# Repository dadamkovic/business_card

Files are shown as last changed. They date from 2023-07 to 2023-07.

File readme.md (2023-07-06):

Project in Progress
----------------------------

A PCB for a simple, low profile business card. Intended to be
programmed with a few simple games. BOM cost as of version 0.1 is ~6$.

Includes: 
- 5 LEDs
- buzzer
- STM32F042F4Px (USB communication)

PCB has cutout for components that are inteded to be mounted 'body in'
to decrease the thickness of the PCB (1.2mm PCB used), to get close to
the business card compactness.

Pictures:

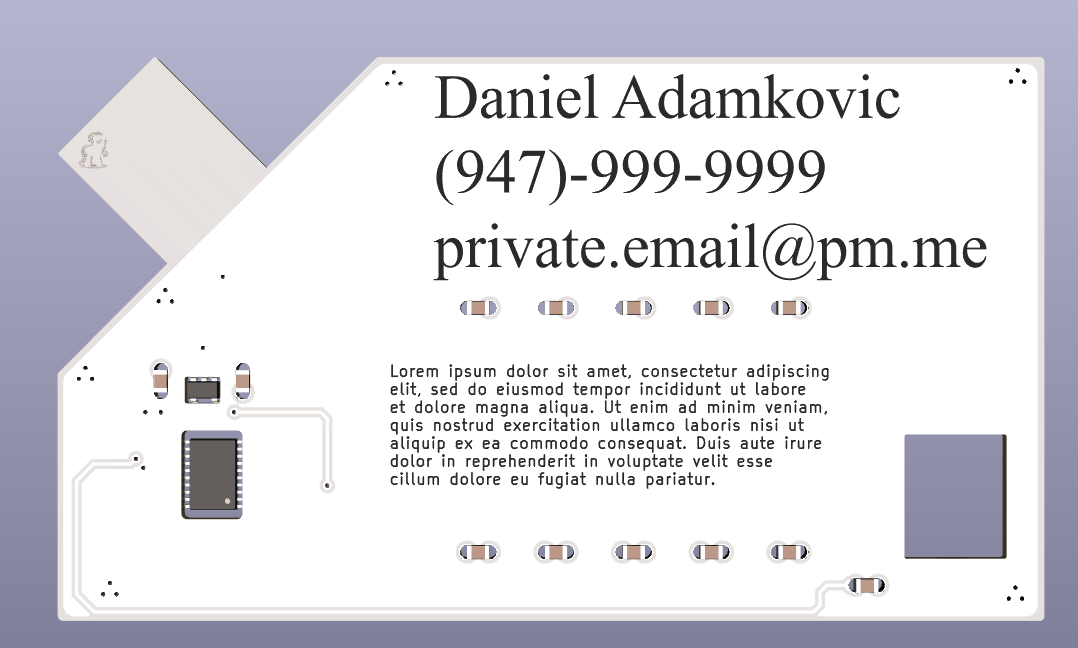
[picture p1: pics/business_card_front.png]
front side

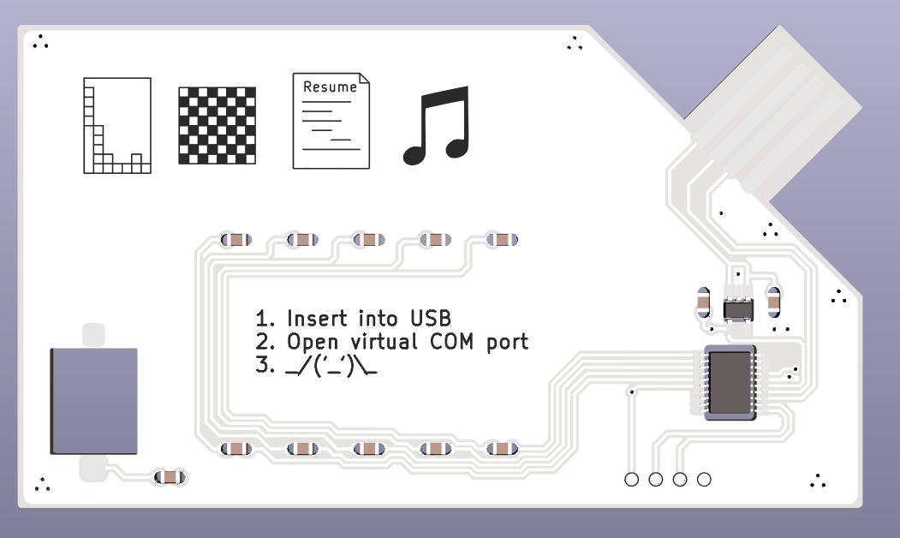
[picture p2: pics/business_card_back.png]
back side


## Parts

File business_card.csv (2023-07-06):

# | Reference | Qty | Value | Footprint | DNP | Source | Price
1 | BZ1 | 1 | Buzzer | User_Buzzer:Buzzer |  | https://www.mouser.com/ProductDetail/AATC/APD-1109-LF?qs=uwxL4vQweFP3stWKjDUYjg%3D%3D | 2.11
2 | C1, C2 | 2 | 1u | User_0805:C_0805_2012Metric |  | https://www.mouser.com/ProductDetail/Samsung-Electro-Mechanics/CL21B105KOFNFNE | 0.065
3 | D1, D2, D3, D4, D5 | 5 | LED | User_0805:C_0805_2012Metric
4 | J1 | 1 | Conn_01x04_Pin | User_PCB_Connector:USB_Conn
5 | R1, R2, R3, R4, R5 | 5 | 2k | User_0805:C_0805_2012Metric
6 | R6 | 1 | 700 | User_0805:C_0805_2012Metric
7 | TP1, TP2, TP3, TP4 | 4 | TestPoint | TestPoint:TestPoint_Pad_D1.0mm
8 | U1 | 1 | STM32F042F4Px | User_uC:Reverse TSSOP-20_4.4x6.5mm_P0.65mm |  | https://www.mouser.com/ProductDetail/STMicroelectronics/STM32F042F4P6?qs=4b8myOmUP%252BvvhAaQx2eFdg%3D%3D | 3.2
9 | U2 | 1 | MIC5504-1.2YM5 | User_Regulator:SOT-23-5 |  | https://www.mouser.com/ProductDetail/Microchip-Technology/MIC5504-3.3YM5-TR?qs=U6T8BxXiZAUmVQ5Zs217qQ%3D%3D | 0.25

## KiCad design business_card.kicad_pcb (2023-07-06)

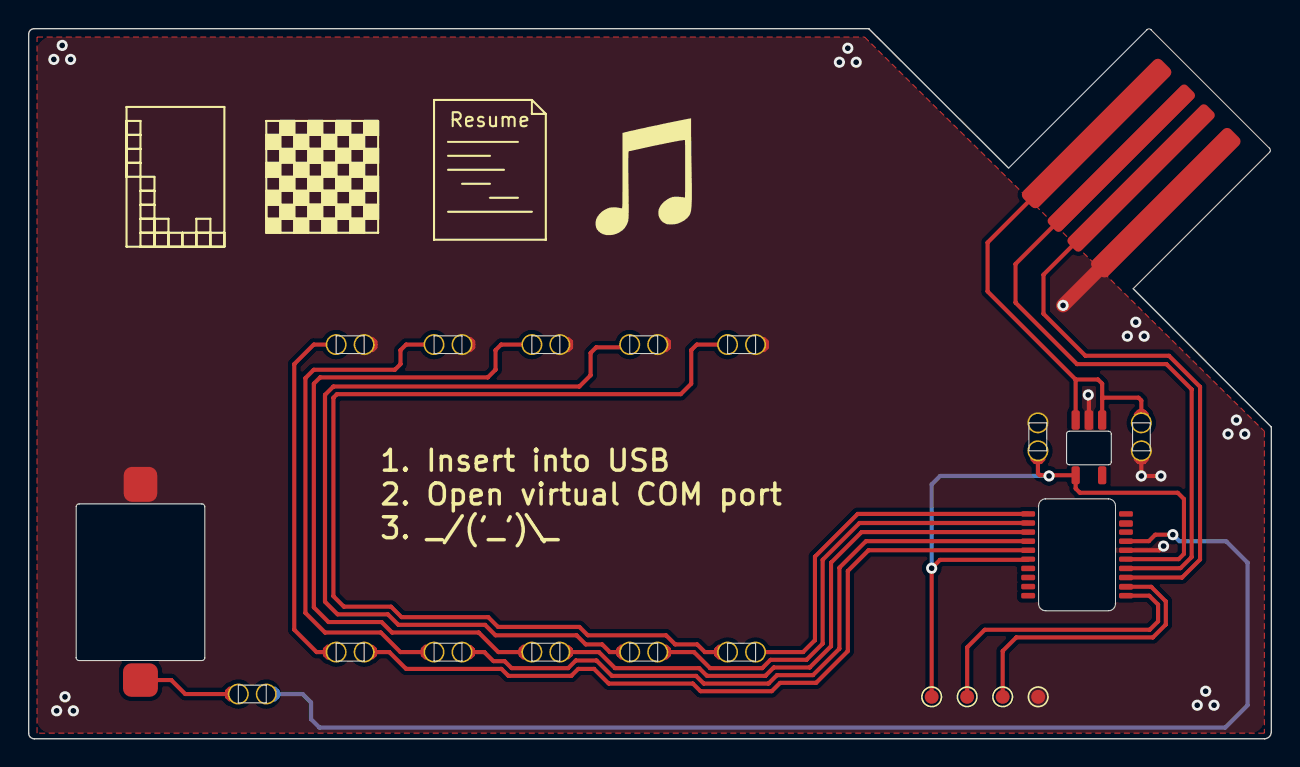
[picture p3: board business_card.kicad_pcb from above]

Board: 2 copper layers, 88.9 x 50.8 mm, 21 parts (0 on the bottom side), 19 nets.

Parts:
BZ1: Buzzer
C1, C2: C_Small; C_0805_2012Metric
D1, D2, D3, D4, D5: LED; C_0805_2012Metric
J1: Conn_01x04_Pin; USB_Conn
R1, R2, R3, R4, R5, R6: R_Small; C_0805_2012Metric
TP1, TP2, TP3, TP4: TestPoint; TestPoint_Pad_D1.0mm
U1: STM32F042F4Px; Reverse TSSOP-20_4.4x6.5mm_P0.65mm
U2: MIC5504-1.2YM5; SOT-23-5

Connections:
/3V3_SUPPLY: C2.1, TP1.1, U1.5 (VDDA), U1.16 (VDD), U2.5 (VOUT)
/5V_USB: C1.1, J1.1, U2.1 (VIN), U2.3 (EN)
/SWDCLK: TP3.1, U1.20 (PA14)
/SWDIO: TP2.1, U1.19 (PA13)
/USB_DM: J1.2, U1.17 (PA9/PA11)
/USB_DP: J1.3, U1.18 (PA10/PA12)
GND: BZ1.1 (-), C1.2, C2.2, D1.1 (K), D2.1 (K), D3.1 (K), D4.1 (K), D5.1 (K), J1.4, TP4.1, U1.15 (VSSA), U2.2 (GND)
unnamed: BZ1.2 (+), R6.1
unnamed: D1.2 (A), R1.2
unnamed: D2.2 (A), R2.2
unnamed: D3.2 (A), R3.2
unnamed: D4.2 (A), R4.2
unnamed: D5.2 (A), R5.2
unnamed: R5.1, U1.6 (PA0)
unnamed: R4.1, U1.7 (PA1)
unnamed: R3.1, U1.8 (PA2)
unnamed: R1.1, U1.9 (PA3)
unnamed: R2.1, U1.10 (PA4)
unnamed: R6.2, U1.14 (PB1)

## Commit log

2023-07-03 Routed version v0.1 of the business card.
    [business_card-B_Cu.gbr, business_card-B_Mask.gbr, business_card-B_Paste.gbr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]
2023-07-06 Added BOM and readme.
    [business_card-B_Cu.gbr, business_card-B_Mask.gbr, business_card-B_Paste.gbr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]
